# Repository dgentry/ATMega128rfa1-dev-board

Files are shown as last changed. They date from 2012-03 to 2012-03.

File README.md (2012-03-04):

##A  Better ATMega 128rfa1 Dev Board

See http://www.sparkfun.com/products/9734

Some of the complaints in the comments that I've started to address:

1) If you solder headers into the battery (for hitec connector), ISP,
and uart pins, you won’t be able to insert the ISP programmer
connector – there isn’t any room! If you use this, put your
battery/uart headers underneath your board. A bit silly, but no other
choice.  
[Moved the ISP header left, hopefully gives enough room]

2) With nothing connected but a fully charged 6V battery, this board still has bad voltage drops when turning on the transmitter. You must solder on a capacitor between ground and 3.3V or it won’t work. I put a 20uF tantelum on it, and the resets went away.
<br>[suggested 20uF tantalum in the C5 silkscreen]

4) The traces look like someone used Eagle CAD auto-route and called it a day, without doing much of any touching up.
<br>[Reduced number of vias by about 50%, made antenna signal lines straighter and kept them on top of the board, beefed up power and ground lines where I could]

My suggestion: get rid of the power jack and then by careful redesign a similar board can be made small enough to fit in a breadboard, maybe even cheap enough for some of the people complaining about the high price tag.
<br>[to do, but not sure that'll make it super small anyway]

Oh heck, if any of you guys at SparkFun are listening, here’s my wish-list for a hypothetical future revision of this board:
1) Drop the regulator, or make it an optional DIY addition.
<br>[You're populating your own board, drop away.  :]

2) Make all of the break out pins on the top and bottom aligned to a 0.1" grid.
<br>[All the pins on the side are aligned.  The three connectors at the bottom/end of the board should probably go up, not down]

3) Add a JTAG port in addition to the ISP port. Feel free to use a 0.05" pitch connector for the JTAG port is space is tight.
<br>[to do]

4) Add a U.FL connector (or at least the landing pattern for it) to the board, so that I can solder off the chip antenna and add a Real antenna without too much headache.
<br>[to do]

The result would be a more affordable and more desirable product. I'd by another one. Or two.

Thanks to JÃ¶rg Wunsch on avrfreaks.com, the problem is that the TST
pin is left floating. After connecting this pin to ground, reset and
power on reset works reliably.
<br>[added solderable/cuttable jumper "GND-TST"]

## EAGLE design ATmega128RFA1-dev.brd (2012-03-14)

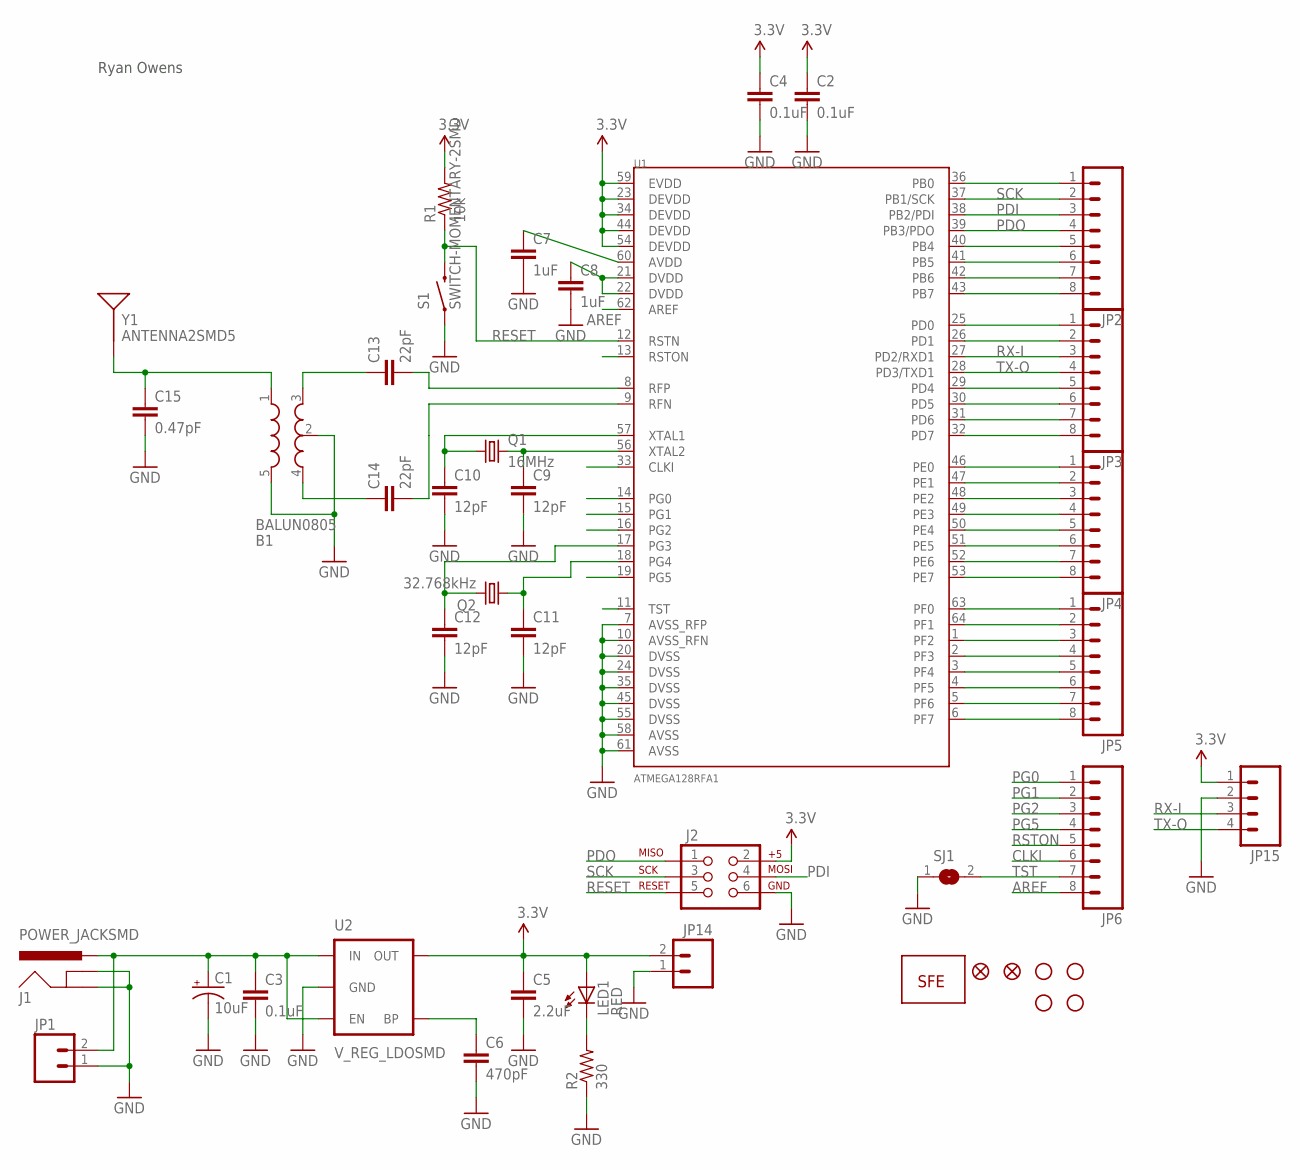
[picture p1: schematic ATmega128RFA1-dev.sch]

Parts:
B1: BALUN0805; BALUN
C1: 10uF; EIA3216
C2, C3, C4: 0.1uF; 0603-CAP
C5: 2.2uF; 0603-CAP
C6: 470pF; 0603-CAP
C7, C8: 1uF; 0805
C9, C10, C11, C12: 12pF; 0603-CAP
C13, C14: 22pF; 0603-CAP
C15: 0.47pF; 0603-CAP
J1: POWER_JACKSMD; POWER_JACK_SMD
J2: AVR_SPI_PRG_6PTH; 2X3
JP1, JP14: M02PTH; 1X02
JP2, JP3, JP4, JP5, JP6: M08; 1X08
JP7: LOGO-SFENEW; SFE-NEW-WEBLOGO
JP8, JP9: FIDUCIAL1X2; FIDUCIAL-1X2
JP10, JP11, JP12, JP13: STAND-OFF
JP15: M04PTH; 1X04
LED1: RED; LED-0603
Q1: 16MHz; CRYSTAL-SMD-5X3
Q2: 32.768kHz; CRYSTAL-32KHZ-SMD
R1: 10k; 0603-RES
R2: 330; 0603-RES
S1: SWITCH-MOMENTARY-2SMD; TACTILE_SWITCH_SMD
SJ1: SJ
U1: ATMEGA128RFA1; QFN-64
U2: V_REG_LDOSMD; SOT23-5
Y1: ANTENNA2SMD5; ANTENNA-CHIP5

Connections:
3.3V: C2.1, C4.1, C5.1, J2.2, JP14.2, JP15.1, LED1.A, R1.2, U1.23 (DEVDD), U1.34 (DEVDD), U1.44 (DEVDD), U1.54 (DEVDD), U1.59 (EVDD), U2.5 (OUT)
AREF: JP6.8, U1.62 (AREF)
CLKI: JP6.6, U1.33 (CLKI)
GND: B1.2 (GND), B1.5 (GND), C1.C (-), C2.2, C3.2, C4.2, C5.2, C6.2, C7.2, C8.2, C9.2, C10.2, C11.2, C12.2, C15.2, J1.GND (GNDBREAK), J1.P$4 (GND), J2.6, JP1.1, JP14.1, JP15.2, R2.1, S1.1, SJ1.1, U1.7 (AVSS_RFP), U1.10 (AVSS_RFN), U1.20 (DVSS), U1.24 (DVSS), U1.35 (DVSS), U1.45 (DVSS), U1.55 (DVSS), U1.58 (AVSS), U1.61 (AVSS), U2.2 (GND)
unnamed: B1.3 (OUT1), C13.1
unnamed: B1.4 (OUT2), C14.1
unnamed: C1.A (+), C3.1, J1.VIN0 (PWR), JP1.2, U2.1 (IN), U2.3 (EN)
unnamed: B1.1 (IN), C15.1, Y1.FEED
unnamed: C8.1, U1.21 (DVDD), U1.22 (DVDD)
unnamed: C14.2, U1.9 (RFN)
unnamed: C13.2, U1.8 (RFP)
unnamed: LED1.C, R2.2
unnamed: C7.1, U1.60 (AVDD)
unnamed: C10.1, Q1.1, U1.57 (XTAL1)
unnamed: C9.1, Q1.3 (2), U1.56 (XTAL2)
unnamed: C12.1, Q2.X2 (2), U1.17 (PG3)
unnamed: C11.1, Q2.X1 (1), U1.18 (PG4)
unnamed: C6.1, U2.4 (BP)
unnamed: JP2.1, U1.36 (PB0)
unnamed: JP2.5, U1.40 (PB4)
unnamed: JP2.6, U1.41 (PB5)
unnamed: JP2.7, U1.42 (PB6)
unnamed: JP2.8, U1.43 (PB7)
unnamed: JP3.1, U1.25 (PD0)
unnamed: JP3.2, U1.26 (PD1)
unnamed: JP3.5, U1.29 (PD4)
unnamed: JP3.6, U1.30 (PD5)
unnamed: JP3.7, U1.31 (PD6)
unnamed: JP3.8, U1.32 (PD7)
unnamed: JP4.1, U1.46 (PE0)
unnamed: JP4.2, U1.47 (PE1)
unnamed: JP4.3, U1.48 (PE2)
unnamed: JP4.4, U1.49 (PE3)
unnamed: JP4.5, U1.50 (PE4)
unnamed: JP4.6, U1.51 (PE5)
unnamed: JP4.7, U1.52 (PE6)
unnamed: JP4.8, U1.53 (PE7)
unnamed: JP5.1, U1.63 (PF0)
unnamed: JP5.2, U1.64 (PF1)
unnamed: JP5.3, U1.1 (PF2)
unnamed: JP5.4, U1.2 (PF3)
unnamed: JP5.5, U1.3 (PF4)
unnamed: JP5.6, U1.4 (PF5)
unnamed: JP5.7, U1.5 (PF6)
unnamed: JP5.8, U1.6 (PF7)
PDI: J2.4, JP2.3, U1.38 (PB2/PDI)
PDO: J2.1, JP2.4, U1.39 (PB3/PDO)
PG0: JP6.1, U1.14 (PG0)
PG1: JP6.2, U1.15 (PG1)
PG2: JP6.3, U1.16 (PG2)
PG5: JP6.4, U1.19 (PG5)
RESET: J2.5, R1.1, S1.3 (2), U1.12 (RSTN)
RSTON: JP6.5, U1.13 (RSTON)
RX-I: JP3.3, JP15.3, U1.27 (PD2/RXD1)
SCK: J2.3, JP2.2, U1.37 (PB1/SCK)
TST: JP6.7, SJ1.2, U1.11 (TST)
TX-O: JP3.4, JP15.4, U1.28 (PD3/TXD1)

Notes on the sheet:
Ryan Owens

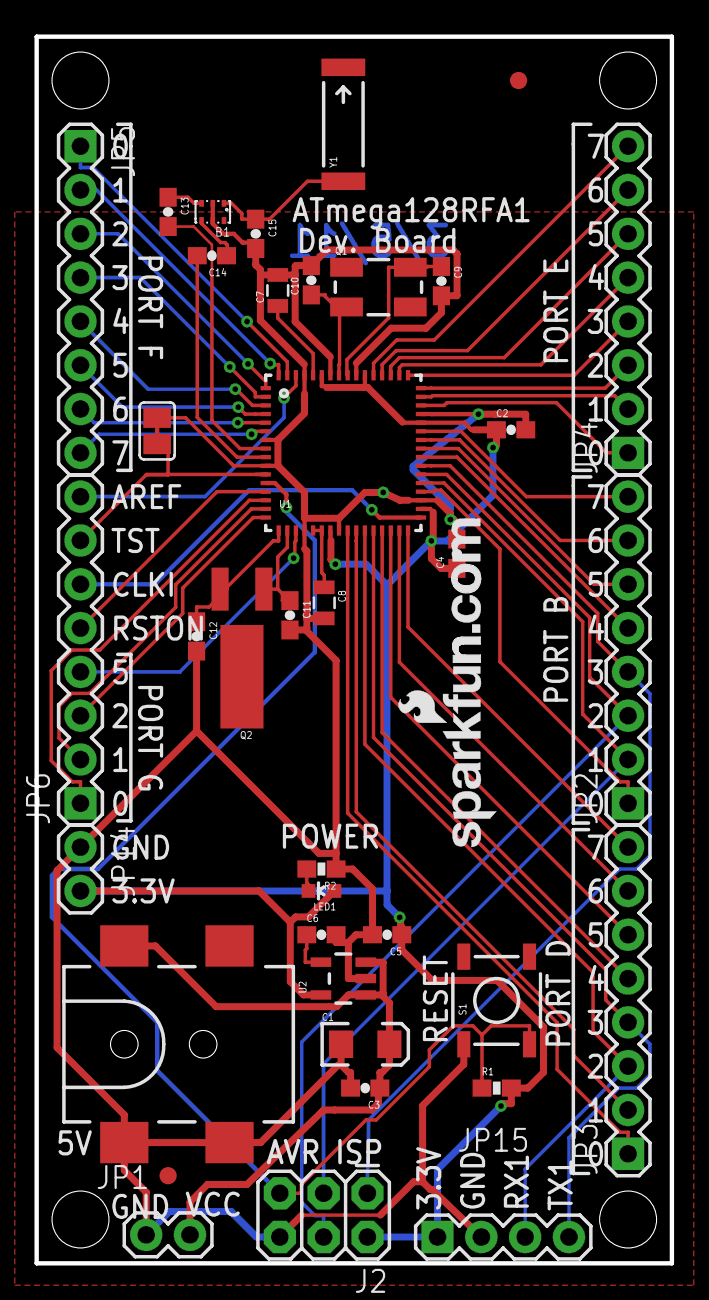
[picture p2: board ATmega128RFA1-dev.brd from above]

Board: 2 copper layers, 36.8 x 71.1 mm, 43 parts (0 on the bottom side), 57 nets.

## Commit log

2012-02-09 New layout and fixes for Sparkfun's similar board.
    [ATmega128RFA1 Dev Board-v11.brd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]
2012-02-11 Got rid of extraneous files
    [ATmega128RFA1 Dev Board-v11.GBL, ATmega128RFA1 Dev Board-v11.GBO, ATmega128RFA1 Dev Board-v11.GBS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]
2012-03-04 Gave the files more reasonable names
    [ATmega128RFA1-dev.brd, ATmega128RFA1-dev.sch]
2012-03-04 Updated README.md with issues and status
    [ATmega128RFA1-dev.brd, ATmega128RFA1-dev.sch]
2012-03-04 Added trace so solder jumper is connected until you cut it.
    [ATmega128RFA1-dev.brd]
2012-03-14 Rearranged CC message so more of the board fits on my display
    [ATmega128RFA1-dev.brd, ATmega128RFA1-dev.sch]

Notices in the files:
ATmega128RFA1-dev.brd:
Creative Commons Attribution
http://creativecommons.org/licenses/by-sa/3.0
